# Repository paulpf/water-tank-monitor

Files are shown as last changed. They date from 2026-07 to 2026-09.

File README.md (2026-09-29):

# Water Tank Monitor (D1 Mini / ESP8266)

ESP8266-basierter Wasserstand-Monitor für den Longzhuo TL-136 Flüssigkeitsstand-Messumformer (4-20 mA, 12-32 VDC).
Liest den Tankfüllstand über einen ADS1115 (I2C) aus und veröffentlicht Füllstand, Höhe, Volumen und Diagnosewerte per MQTT
(z. B. für ioBroker). WiFi-Konnektivität und OTA-Updates sind eingebaut.

## Inhaltsverzeichnis
- [Hardware](#hardware)
- [Verdrahtung](#verdrahtung)
- [Funktionsprinzip 4-20 mA](#funktionsprinzip-4-20-ma)
- [Projektstruktur](#projektstruktur)
- [Konfiguration](#konfiguration)
- [Build und Upload](#build-und-upload)
- [MQTT](#mqtt)
- [Serial-Ausgabe](#serial-ausgabe)
- [Fehlersuche](#fehlersuche)
- [OTA-Updates](#ota-updates)
- [Security](#security)
- [Tests und CI](#tests-und-ci)

---

## Hardware

| Bauteil | Beschreibung |
|---|---|
| WeMos D1 Mini | ESP8266-Mikrocontroller, 3,3 V Logik |
| Longzhuo TL-136 | 2-Draht 4-20 mA Füllstandssensor, 12-32 VDC Loop-Speisung |
| Boost-Converter | 5 V USB → 24 V DC für den Sensor-Loop (Trimmer auf 24 V einstellen) |
| 4-20 mA Empfänger | Wandelt Stromsignal in Spannung: I+ / I– Eingang, 0–3,3 V Ausgang |
| ADS1115 | 16-Bit I²C ADC (Adafruit), I²C-Adresse 0x48 (ADDR → GND), GAIN_ONE ±4,096 V |

> **Auflösung:** ADS1115 liefert 0,125 mV/Bit (16-Bit) statt 3,2 mV/Bit des ESP8266-internen ADC — 25× besser.  
> **Kein separates Netzteil nötig:** Der Boost-Converter erzeugt die 24 V Loop-Spannung direkt aus USB 5 V.

---

## Platinenlayout / Verdrahtung

Bestückung und Brücken

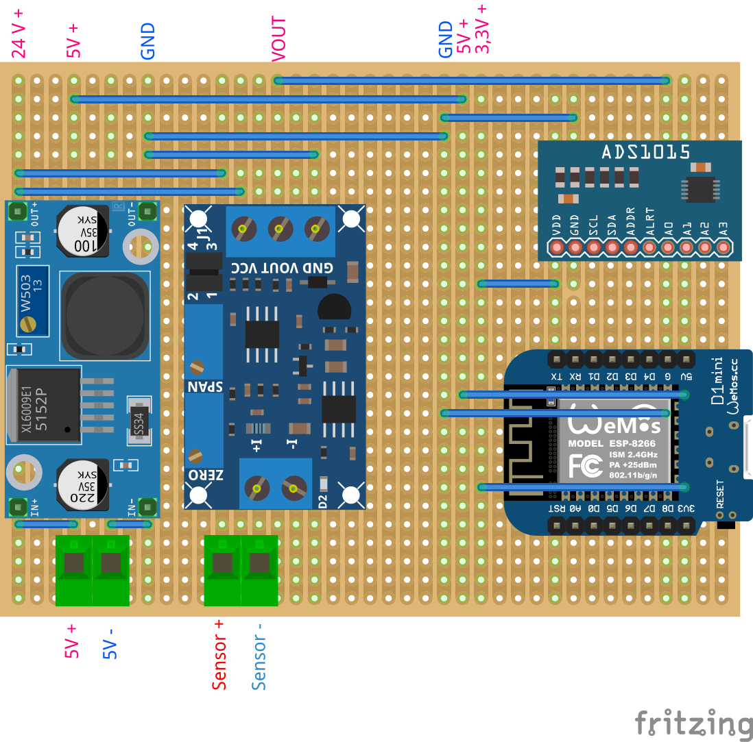
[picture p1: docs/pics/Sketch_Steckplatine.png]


Trennungsstellen der Leiterbahnen (Cut-Lines) auf der Platine

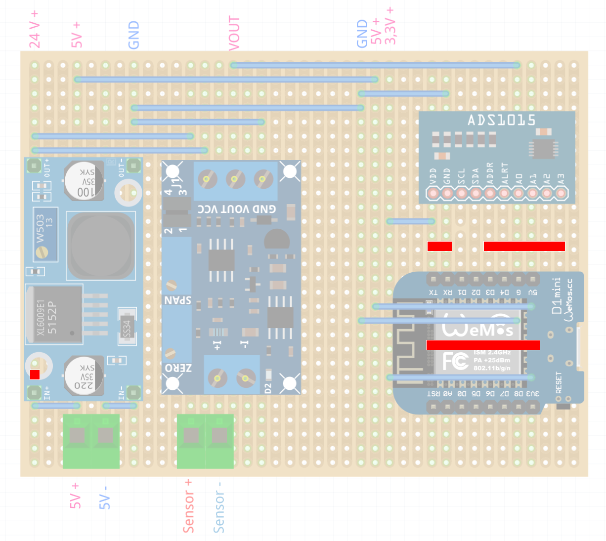
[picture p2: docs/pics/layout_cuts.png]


### Klemmbelegung Schritt für Schritt

| Schritt | Von | Nach | Beschreibung |
|---|---|---|---|
| 1 | D1 Mini **5V-Pin** | Boost-Converter IN+ | 5V vom USB-VBUS (Polyfuse 500 mA, passt) |
| 2 | Boost-Converter OUT+ (24 V) | TL-136 Braun (+) | Loop-Spannung |
| 3 | TL-136 Blau (–) | Empfänger I+ | 4-20 mA Signal |
| 4 | Empfänger I– | GND-Schiene | Loop-Rückleitung |
| 5 | Empfänger Vout | ADS1115 **A0** | Spannungssignal 0–3,3 V |
| 6 | ADS1115 **SCL** | D1 Mini **D1** | I²C Takt |
| 7 | ADS1115 **SDA** | D1 Mini **D2** | I²C Daten |
| 8 | ADS1115 **VDD** | D1 Mini **3V3** | ADS1115 Versorgung |
| 9 | ADS1115 **ADDR** | GND-Schiene | I²C-Adresse 0x48 |
| 10 | D1 Mini **GND** | GND-Schiene | Gemeinsame Masse |
| 11 | USB-Kabel | D1 Mini (Micro-USB) | Einzige externe Stromquelle |

> **GND-Schiene:** Boost-Converter-GND, Empfänger-GND, ADS1115-GND und D1-Mini-GND müssen alle verbunden sein.  
> **Strombudget:** ESP8266 ~170 mA + Boost ~57 mA + Rest ~6 mA = ~230 mA gesamt — USB 2.0 (500 mA) hat ausreichend Reserve.

### Kalibrierung des Signalempfängers

Der 4-20 mA Empfänger hat zwei Trimmer: **ZERO** (Nullpunkt) und **SPAN** (Vollausschlag).
Ziel: 4 mA → 0,00 V, 20 mA → SPAN-Trimmer auf Maximum drehen und gemessenen Wert in `config.h` eintragen (dieser Receiver: **3,153 V**).

#### Schritt 1 – ZERO einstellen (Nullpunkt, leerer Tank)

> **Wichtig:** ZERO kalibriert den **4 mA-Punkt**. Ohne Sensor oder Widerstand-Simulator fließt kein Strom im Loop — der Trimmer lässt sich dann nicht sinnvoll einstellen.

- Multimeter (DC-Spannung) zwischen **VOUT** und **GND** der Receiver-Platine klemmen
- Tank leeren (Sensor angeschlossen) **oder** Widerstand-Simulator für 4 mA an **I+** / **I–** anschließen (s. u.)
- **ZERO-Trimmer** drehen bis Spannung an **VOUT** = **0,00 V**
- Drehrichtung: **Uhrzeigersinn erhöht** die Ausgangsspannung (bei den meisten Modulen) —  
  kurze Probedrehung machen und Multimeter beobachten; bei falschem Effekt Richtung umkehren

#### Schritt 2 – SPAN einstellen (Vollausschlag, voller Tank)

- Tank füllen **oder** 20 mA in **I+** / **I–** einspeisen (Widerstand-Simulator, s. u.)
- **SPAN-Trimmer** drehen bis Spannung an **VOUT** = **3,30 V**
- Drehrichtung: ebenfalls **Uhrzeigersinn erhöht** — kurze Probedrehung zur Verifikation

#### Schritt 3 – Iterieren

ZERO und SPAN beeinflussen sich gegenseitig leicht.  
Schritte 1 und 2 zwei- bis dreimal wiederholen bis beide Punkte stabil sind.

#### Trimmer und Potentiometer prüfen (vor dem Einbau)

Vor der Kalibrierung sicherstellen, dass Trimmer und Poti (für Simulator-Schaltung) intakt sind:

1. **Gesamtwiderstand messen** — Multimeter auf Ω, die beiden äußeren Anschlüsse messen:  
   Soll = Aufdruck (z. B. 5 kΩ, 10 kΩ). Abweichung > 20 % → Bauteil defekt.

2. **Schleifer auf Gleichmäßigkeit prüfen** — Multimeter auf Ω zwischen Schleifer (Mittelanschluss) und einem äußeren Anschluss, Trimmer/Poti langsam von Anschlag zu Anschlag drehen:  
   Wert soll sich **kontinuierlich und gleichmäßig** ändern (0 Ω bis Maximalwert).  
   Sprünge oder tote Bereiche → Bauteil verbraucht oder oxidiert → tauschen.

3. **Auf Unterbrechung testen** — Multimeter auf Durchgang (Piepton-Modus), Schleifer auf Mitte stellen, alle drei Anschlüsse paarweise prüfen: jedes Paar sollte Durchgang haben.

#### 4 mA und 20 mA simulieren ohne Tank

TL-136 abstecken, Widerstand in den Loop schalten:

```
Boost OUT+ (24 V) → [R_sim] → Multimeter (mA) → I+  [Receiver]  I– → GND
```

```
I = U / R    →    R = U / I

4 mA  (ZERO): R = 24 V / 4 mA  = 6000 Ω  → 5,6 kΩ + 390 Ω in Reihe
20 mA (SPAN): R = 24 V / 20 mA = 1200 Ω  → 1 kΩ + 200 Ω in Reihe

Achtung: 560 Ω wären bei 24 V ≈ 42 mA → Receiver-Schaden!
```

Multimeter in Reihe (Strommessung) ist die präziseste Methode — Widerstandstoleranzen ausgleichen durch Iterieren.

#### Hinweis: ZERO-Drift bei 24 V

Bei 24 V Loop-Spannung kann der ZERO-Punkt leicht über 0 V liegen.  
Liegt **VOUT** bei leerem Tank z. B. auf 0,05 V statt 0,00 V,  
den ZERO-Trimmer so weit wie möglich gegen 0 V trimmen — der Rest wird durch die **Software-Kalibrierung** (s. u.) korrigiert.

---

## Funktionsprinzip 4-20 mA

Der TL-136 ist ein **2-Draht Loop-Transmitter**: Er moduliert den Strom im
Loop proportional zum Füllstand. Der **4-20 mA Signalempfänger** wandelt
diesen Strom in eine Spannung um, die der **ADS1115** (Kanal A0, 16 Bit, `GAIN_ONE` = ±4,096 V, 0,125 mV/Bit) misst.

| Loop-Strom | Spannung an ADS1115 A0 (kalibriert, `SENSOR_VREF` = 3,153 V) |
|---|---|
| 4 mA | 0,000 V |
| 8 mA | 0,788 V |
| 12 mA | 1,577 V |
| 16 mA | 2,365 V |
| 20 mA | 3,153 V |

**Umrechnung** (in [src/domain/tankmodel.cpp](src/domain/tankmodel.cpp)):

```
Strom    = (Spannung / SENSOR_VREF) × 16 + 4          [mA]  ← nur für Diagnose und Gültigkeitsprüfung
Höhe     = Kalibriertabelle SENSOR_CAL_TABLE(Spannung) [cm]  ← gesamte Wasserhöhe ab Tankboden
Füllstand = (Höhe − 13 cm) / (210 cm − 13 cm) × 100    [%]   ← 0 % = Sensorposition, 100 % = Ablauf
Volumen  = Zylinder (r = 1 m) bis 198 cm, darüber linear bis 6500 L bei 210 cm   [L]
Überlauf = Volumen − 6500 L, falls positiv                [L]
```

Die Höhe folgt nicht linear aus dem Strom, sondern aus gemessenen Stützpunkten (siehe
[Software-Kalibrierung](#software-kalibrierung-kalibriertabelle)). Oberhalb 210 cm kann der Füllstand über 100 % steigen.

Werte außerhalb 3,8–20,5 mA werden als Sensor-/Verdrahtungsfehler geloggt, per MQTT als `tank/valid = false`
gemeldet und die Messwerte (Füllstand, Höhe, Volumen) dann nicht veröffentlicht.

---

## Projektstruktur

```text
water-tank-monitor/
├── src/
│   ├── app/
│   │   ├── application.cpp / .h    # Hauptschleife: Timer, Publizieren, MQTT-Befehle
│   │   └── main.cpp                # Objekte anlegen, setup()/loop()
│   ├── config/
│   │   ├── config.h                # Konstanten: Topics, Timings, Sensor, Tankgeometrie, Kalibriertabelle
│   │   └── systemconfig.h          # Zur Laufzeit per MQTT änderbare Werte
│   ├── domain/                     # Reine Logik ohne Arduino, nativ getestet
│   │   ├── tankmodel.cpp / .h      # Spannung → Strom, Höhe, Prozent, Volumen, Überlauf
│   │   ├── tanklevel.h             # Wertobjekt eines Messwerts
│   │   ├── mqttcommands.cpp / .h   # Payload-Parser für Intervall und 0/1
│   │   └── intervaltimer.h         # millis()-überlaufsicherer Intervall-Timer
│   └── infrastructure/             # Hardware und Netzwerk
│       ├── levelsensor.cpp / .h    # ADS1115 auslesen
│       ├── wifimanager.cpp / .h    # WLAN verbinden; Reconnect macht das SDK, Fallback nach 5 min
│       ├── mqttmanager.cpp / .h    # MQTT folgt dem WLAN-Zustand, LWT, Re-Subscribe
│       ├── otamanager.cpp / .h     # ArduinoOTA, fail-closed ohne Passwort
│       ├── watchdog.cpp / .h       # Software-Watchdog
│       └── trace.cpp / .h          # Serial-Logging
├── test/native/                    # Unity-Tests für src/domain
├── scripts/
├── platformio.ini
└── README.md
```

Externe Secrets (nicht im Repo):
```text
../_secrets/
├── WifiSecret.h        # WIFI_SSID, WIFI_PWD
├── MqttSecret.h        # MQTT_USER, MQTT_PWD
├── OtaSecret.h         # OTA_PASSWORD
└── last_ota_ip.txt     # zuletzt verwendete OTA-IP (automatisch)
../_config/
└── MqttConfig.h        # MQTT_SERVER_IP, MQTT_SERVER_PORT
```
Anlegen mit `scripts/setup_secrets.ps1` bzw. `scripts/setup_secrets.sh`.

---

## Konfiguration

Alle Konstanten liegen in [src/config/config.h](src/config/config.h).

### Sensor-Parameter

```cpp
constexpr uint8_t  SENSOR_ADS_I2C_ADDR      = 0x48;   // ADDR-Pin → GND
constexpr uint8_t  SENSOR_ADS_CHANNEL       = 0;      // ADS1115 Kanal A0
constexpr float    SENSOR_VREF              = 3.153f; // gemessener Vollausschlag des Empfängers (20 mA) [V]
constexpr uint32_t SENSOR_READ_INTERVAL_MS  = 500;    // Standard-Leseintervall, per MQTT änderbar
constexpr uint32_t MQTT_PUBLISH_INTERVAL_MS = 1000;   // Standard-Sendeintervall, per MQTT änderbar
```

`SENSOR_VREF` wird nur für den Stromwert (`currentMa`) und die Gültigkeitsprüfung (3,8–20,5 mA) verwendet.
Voraussetzung: Der Signalempfänger ist auf **4 mA → 0 V** kalibriert (ZERO/SPAN-Trimmer, s. Abschnitt
[Kalibrierung des Signalempfängers](#kalibrierung-des-signalempfängers)).

### Software-Kalibrierung (Kalibriertabelle)

Die Wasserhöhe wird über die Tabelle `SENSOR_CAL_TABLE` in `config.h` aus der Spannung berechnet: zwischen zwei Punkten
linear interpoliert, unterhalb des ersten Punkts auf die Sensorhöhe begrenzt, oberhalb des letzten mit der Steigung des
letzten Abschnitts extrapoliert. Höhe ist die gesamte Wasserhöhe ab Tankboden (wie mit dem Maßband gemessen).

```cpp
constexpr SensorCalPoint SENSOR_CAL_TABLE[] = {
    { 0.000f,  13.0f },   // Sensorposition
    { 0.2277f, 20.0f },   // gemessen
    { 2.2419f, 210.0f },  // gemessen
    ...
};
```

**Neuen Messpunkt aufnehmen:**

1. Kalibriermodus einschalten: `1` auf `water-tank-monitor/config/calibrationMode/set` (Werte alle 500 ms)
2. Wasserhöhe mit dem Maßband messen
3. Spannung aus `water-tank-monitor/tank/voltageV` ablesen
4. Punkt `{ Spannung, Höhe }` in `SENSOR_CAL_TABLE` einfügen (Spannungen aufsteigend sortiert)
5. `pio test -e native` ausführen (prüft u. a. alle Tabellenpunkte), Firmware bauen und flashen
6. Kalibriermodus ausschalten: `0` auf `.../calibrationMode/set`

### Libraries

Versionen sind in `platformio.ini` exakt festgelegt (Adafruit ADS1X15, Adafruit BusIO, PubSubClient) und werden
automatisch über PlatformIO installiert.

### WiFi Credentials

Datei: `../_secrets/WifiSecret.h`
```cpp
#define WIFI_SSID "DEIN_NETZWERK"
#define WIFI_PWD  "DEIN_PASSWORT"
```

### OTA-Passwort

Datei: `../_secrets/OtaSecret.h`
```cpp
#define OTA_PASSWORD "dein_ota_passwort"
```

OTA ist **fail-closed**: ohne gesetztes Passwort und
`OTA_ALLOW_INSECURE_NO_PASSWORD false` bleibt OTA deaktiviert.

---

## Build und Upload

### USB (erstmaliger Flash)

```powershell
pio run -e d1-mini-usb
pio run -e d1-mini-usb -t upload -t monitor --upload-port COM3
```

### OTA (Folge-Updates)

Interaktives PowerShell-Skript (fragt IP ab, liest OTA-Passwort automatisch):

```powershell
.\scripts\upload_ota.ps1
```

Alternativ (Windows Batch):
```bat
scripts\upload_ota.bat
```

Die zuletzt verwendete IP wird in `../_secrets/last_ota_ip.txt` gespeichert.

---

## MQTT

Alle Topics beginnen mit `water-tank-monitor/`. Werte veröffentlicht das Gerät retained, außer `system/rssi`.

| Topic | Inhalt |
|---|---|
| `tank/levelPercent`, `tank/heightCm`, `tank/volumeLiters`, `tank/volumeOverflowLiters` | Messwerte (nur bei gültigem Sensorwert) |
| `tank/currentMa`, `tank/voltageV`, `tank/valid` | Rohwerte und Gültigkeit (`true`/`false`) |
| `system/health` | JSON mit Sensor-, WLAN-, Heap- und OTA-Status |
| `system/ip`, `system/rssi` | IP-Adresse, WLAN-Signalstärke |
| `system/status` | `online`, bzw. `offline` als Last Will |
| `config/readIntervalMs`, `config/publishIntervalMs`, `config/calibrationMode` | aktuelle Einstellungen |

Befehle (auf das jeweilige Topic schreiben):

| Topic | Gültige Werte |
|---|---|
| `config/readIntervalMs/set`, `config/publishIntervalMs/set` | nur Ziffern, ohne führende Null, ab 500 (ms); sehr große Werte (bis 4294967295) setzen Lesen bzw. Senden praktisch aus |
| `config/calibrationMode/set` | `1` (Lesen und Senden alle 500 ms) oder `0` |
| `command/reset` | `1` startet das Gerät neu, alles andere wird ignoriert |

Ungültige Werte werden ignoriert und im Serial-Log als Warnung gemeldet. Frühere Firmware-Versionen haben z. B. `12abc`
als 12 ms übernommen, Werte unter 500 ms akzeptiert und den Rohtext ins State-Topic zurückgeschrieben.

---

## Serial-Ausgabe

Baud: **115200**

```
[INFO] Application setup started
[INFO] ADS1115 ready
[INFO] MqttManager setup complete
[INFO] Application setup complete
[INFO] WiFi connected, IP: 192.168.178.42
[INFO] Setting up OTA...
[INFO] OTA initialized successfully
[INFO] MQTT connecting...
[INFO] MQTT connected
[INFO] MQTT connected - publishing initial values
[INFO] Tank: 47.3% | 106.1 cm | 3333 L | 11.57 mA
[WARNING] Sensor out of range: 0.00 mA - check wiring    ← Kabel offen oder Kurzschluss
```

---

## Fehlersuche

### Messpunkte & Sollwerte

Alle Spannungen gegen GND-Schiene. Multimeter DC-Volt, Loop-Strom in Reihe.

| Messpunkt | Instrument | Sollwert |
| --- | --- | --- |
| Boost OUT+ | Multimeter | **24 V ±0,5 V** |
| Loop-Strom (in Reihe) | Multimeter mA | **4–20 mA** |
| Receiver **VOUT** | Multimeter | **0,00–3,30 V** (proportional zum Füllstand) |
| ADS1115 A0 | Multimeter | identisch mit Receiver **VOUT** |
| ADS1115 VDD | Multimeter | **3,30 V ±0,1 V** |
| ADS1115 ADDR | Multimeter | **0 V** (→ I²C-Adresse 0x48) |
| I²C SCL (D1 Mini D1) | Oszi | **100 kHz** Takt, aktiv beim Lesen |
| I²C SDA (D1 Mini D2) | Oszi | Datenpulse synchron mit SCL |
| Boost OUT+ Ripple | Oszi AC-Kopplung | **< 200 mV pp** |

---

### Fehlerbild: `[WARNING] Sensor out of range: … mA - check wiring`

Tritt auf wenn `currentMa < 3,8` oder `currentMa > 20,5`. Schritt für Schritt eingrenzen:

```
1. Boost-Converter prüfen
   → Multimeter an OUT+ vs GND
   → < 20 V?  → Trimmer nachstellen oder Boost defekt
   → 0 V?     → D1 Mini 5V-Pin prüfen (USB-Verbindung, Polyfuse)

2. Loop-Strom prüfen
   → Multimeter (mA) in Serie: TL-136(–) Blau → Receiver I+
   → 0 mA?    → Offener Kreis: Kabel gebrochen oder TL-136 defekt
   → > 21 mA? → TL-136 übersteuert oder Kurzschluss im Loop
   → 4–20 mA? → Loop OK → weiter mit Schritt 3

3. Receiver-Ausgang prüfen
   → Multimeter (DC-V) an VOUT vs GND der Receiver-Platine
   → 4 mA im Loop → VOUT sollte ~0,0 V sein
   → 20 mA im Loop → VOUT sollte ~3,3 V sein
   → Abweichung → ZERO/SPAN-Trimmer nachjustieren (siehe Kalibrierung)

4. ADS1115-Versorgung prüfen
   → VDD = 3,3 V?
   → ADDR = 0 V? (I²C-Adresse 0x48)
   → GND mit D1 Mini GND verbunden?

5. I²C-Bus prüfen
   → Oszi an SCL (D1) und SDA (D2), Trigger: fallende Flanke SCL
   → Kein Signal → Kabel unterbrochen oder ADS1115 defekt
   → Signal vorhanden → I²C läuft, Firmware-Problem unwahrscheinlich
```

---

### Fehlerbild: Wert springt oder ist verrauscht

**Boost-Ripple (Oszi, AC-Kopplung, 50 mV/div, 20 µs/div):**

- Ripple > 500 mV pp → 100 µF / 25 V Elko direkt an Boost OUT+/GND nachrüsten
- Spitzen synchron mit WiFi-Bursts (alle ~100 ms) → zusätzlich 100 µF an D1 Mini 5V/GND

**I²C-Signalqualität (Oszi, 2 V/div, 5 µs/div):**

- Flanken stark abgerundet → Pull-up-Widerstand fehlt oder zu groß → 4,7 kΩ von SCL/SDA nach 3,3 V
- Idealbild: steile Rechteckflanken, 100 kHz, High-Pegel ~3,3 V

---

### Fehlerbild: Angezeigter %-Wert weicht vom tatsächlichen Füllstand ab

Kalibrierungstabelle in `src/config/config.h` ergänzen:

1. Loop-Strom mit Multimeter auf einen bekannten Wert einstellen (z. B. 12 mA = 50 %)
2. Receiver **VOUT** messen → dieser Spannungswert ist der neue Tabellenpunkt
3. Tatsächliche Gesamthöhe ab Tankboden (Maßband) notieren
4. Eintrag in `SENSOR_CAL_TABLE` hinzufügen: `{ gemessene_V, tatsächliche_Höhe_cm }`
5. Firmware neu bauen und flashen

Mehr Stützpunkte = genauere Kurve. Punkte müssen aufsteigend nach Spannung sortiert sein.

---

### TL-136 ohne Wasser simulieren (Widerstands-Methode)

TL-136 abstecken, Widerstand + Multimeter (mA) in Reihe in den Loop einsetzen:

```
Boost OUT+ (24 V) → [R_sim] → Multimeter (mA) → Receiver I+ → Receiver I– → GND
```

| Simulation | Strom | R_gesamt | Praktischer Wert |
| --- | --- | --- | --- |
| Leerer Tank (ZERO) | 4 mA | 6000 Ω | 5,6 kΩ + 390 Ω |
| Halbvoll | 12 mA | 2000 Ω | 1,8 kΩ + 180 Ω |
| Voller Tank (SPAN) | 20 mA | 1200 Ω | 1 kΩ + 180 Ω |

> Widerstandswert immer mit Multimeter (mA in Reihe) verifizieren — Receiver-Innenwidertand (~150–250 Ω) ist bereits eingerechnet.  
> **Achtung:** 560 Ω wären bei 24 V ≈ 42 mA → Receiver-Schaden.

---

### Schnell-Checkliste

```
□ Boost OUT+ = 24 V DC
□ Loop-Strom mit angeschlossenem Sensor: 4–20 mA
□ Receiver VOUT bei 4 mA  → 0,00 V (ZERO-Trimmer)
□ Receiver VOUT bei 20 mA → 3,153 V (SPAN-Trimmer Maximum, gemessen)
□ ADS1115 VDD = 3,30 V
□ ADS1115 ADDR = 0 V (Adresse 0x48)
□ I²C SCL aktiv beim Lesen (Oszi)
□ Boost-Ripple < 200 mV pp (Oszi, AC-Kopplung)
□ Serial: kein [WARNING] bei korrektem Loop-Strom
```

---

## OTA-Updates

Skript `scripts/upload_ota.ps1`:
- Liest `OTA_PASSWORD` direkt aus `../_secrets/OtaSecret.h`
- Fragt die Geräte-IP ab (letzter Wert als Vorschlag)
- Startet `pio run -e d1-mini-ota -t upload --upload-port <IP>`

---

## Security

- OTA nur in vertrauenswürdigen Netzen aktivieren
- Keine Secrets ins Repository committen
- `OTA_PASSWORD` immer setzen (`OTA_ALLOW_INSECURE_NO_PASSWORD false`)
- Bei WLAN-Ausfall: automatischer Reconnect durch das ESP8266-SDK; nach 5 min ohne Verbindung startet die Firmware den Verbindungsaufbau neu

---

## Tests und CI

```powershell
pio run -e d1-mini-usb          # Firmware-Build
pio test -e native              # Unit-Tests (benötigt gcc/g++ lokal)
```

Die Unit-Tests kompilieren den echten Code aus `src/domain/` für den PC (`test_build_src = yes`):
Kalibrierung und Tankgeometrie, MQTT-Payload-Parser und Intervall-Timer.
Unter Windows liefert z. B. `winget install BrechtSanders.WinLibs.POSIX.UCRT` den nötigen gcc/g++.

CI-Workflow: `.github/workflows/ci.yml` (Firmware-Build und Unit-Tests bei Push auf `main` und bei Pull Requests auf `main`)

### Build-Cache leeren

```powershell
Remove-Item -Recurse -Force .pio\build
```

---

## Referenzen

- [Arduino Core für ESP8266](https://github.com/esp8266/Arduino)
- [ArduinoOTA (ESP8266)](https://arduino-esp8266.readthedocs.io/en/latest/ota_updates/readme.html)
- [PlatformIO](https://platformio.org)
- [WeMos D1 Mini Pinout](https://www.wemos.cc/en/latest/d1/d1_mini.html)

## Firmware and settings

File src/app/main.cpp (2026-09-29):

#include "application.h"
#include "config.h"

WifiManager wifiManager;
OtaManager otaManager;
SystemConfig systemConfig;
LevelSensor levelSensor;
MqttManager mqttManager;
Watchdog watchdog;
Application app(wifiManager, otaManager, systemConfig, levelSensor, mqttManager, watchdog);

void setup()
{
  Serial.begin(SERIAL_BAUD_RATE);
  delay(SERIAL_STARTUP_DELAY_MS);

  app.setup();
}

void loop()
{
  app.loop();
}

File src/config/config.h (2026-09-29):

#ifndef CONFIG_H
#define CONFIG_H

#include <stdint.h>

// Compile-time configuration: device identity, timings, MQTT topics,
// sensor hardware and tank geometry. Secrets live outside the repository
// (../_secrets, ../_config), see scripts/setup_secrets.*.

// Serial configuration
#define SERIAL_BAUD_RATE 115200
constexpr uint32_t SERIAL_STARTUP_DELAY_MS = 500;

// System timings (in milliseconds)
#define WATCHDOG_TIMEOUT 30000

// Trace level for logging
#define TRACE_LEVEL TraceLevel::INFO

// OTA configuration
#define ENABLE_OTA true
#if defined(ARDUINO_ARCH_ESP8266)
constexpr uint16_t OTA_PORT = 8266;
#else
constexpr uint16_t OTA_PORT = 3232;
#endif
// Security default: fail closed if no OTA password is configured
#define OTA_ALLOW_INSECURE_NO_PASSWORD false

// Device identity
#define DEVICE_NAME "water-tank-monitor"

// WiFi configuration
// The SDK auto-reconnects; after this long without WiFi the firmware calls
// WiFi.begin() again as a fallback (and repeats at this interval).
constexpr uint32_t WIFI_FALLBACK_BEGIN_MS = 5UL * 60UL * 1000UL;

// Application loop behavior
constexpr uint32_t STATUS_PRINT_INTERVAL_MS = 30000;

// MQTT configuration
constexpr uint32_t MQTT_RETRY_INTERVAL_MS  = 5000;
#define MQTT_TOPIC_LEVEL_PERCENT       DEVICE_NAME "/tank/levelPercent"
#define MQTT_TOPIC_HEIGHT_CM           DEVICE_NAME "/tank/heightCm"
#define MQTT_TOPIC_VOLUME_LITERS       DEVICE_NAME "/tank/volumeLiters"
#define MQTT_TOPIC_VOLUME_OVERFLOW_L   DEVICE_NAME "/tank/volumeOverflowLiters"
#define MQTT_TOPIC_CURRENT_MA          DEVICE_NAME "/tank/currentMa"
#define MQTT_TOPIC_VOLTAGE_V           DEVICE_NAME "/tank/voltageV"
#define MQTT_TOPIC_VALID               DEVICE_NAME "/tank/valid"
#define MQTT_TOPIC_READ_INTERVAL_MS    DEVICE_NAME "/config/readIntervalMs"        // state (retained, device publishes)
#define MQTT_TOPIC_READ_INTERVAL_SET   DEVICE_NAME "/config/readIntervalMs/set"    // command (write here to change it)
#define MQTT_TOPIC_PUBLISH_INTERVAL_MS  DEVICE_NAME "/config/publishIntervalMs"     // state (retained, device publishes)
#define MQTT_TOPIC_PUBLISH_INTERVAL_SET DEVICE_NAME "/config/publishIntervalMs/set" // command (write here to change it)
#define MQTT_TOPIC_CALIBRATION_MODE     DEVICE_NAME "/config/calibrationMode"       // state (retained, "1"/"0")
#define MQTT_TOPIC_CALIBRATION_MODE_SET DEVICE_NAME "/config/calibrationMode/set"   // command ("1"=on, "0"=off)
constexpr uint32_t CALIBRATION_INTERVAL_MS = 500; // read+publish cadence while calibrationMode is on
#define MQTT_TOPIC_RSSI                DEVICE_NAME "/system/rssi"
#define MQTT_TOPIC_IP                  DEVICE_NAME "/system/ip"
#define MQTT_TOPIC_HEALTH              DEVICE_NAME "/system/health"  // JSON: sensor + system diagnostics
#define MQTT_TOPIC_COMMAND_RESET       DEVICE_NAME "/command/reset"  // payload "1" triggers ESP.restart(), anything else is ignored
constexpr uint32_t MQTT_RSSI_INTERVAL_MS = 5000;

// TL-136 4-20mA level sensor via signal conditioner + ADS1115 (I2C, 16-bit ADC)
// Hardware: USB 5V → Boost converter → 24V loop → TL-136 → 4-20mA receiver
//           → ADS1115 A0 (I2C) → D1 Mini D1/SCL + D2/SDA
// Signal conditioner (SPAN/ZERO trimmer): 4 mA → 0 V, 20 mA → SENSOR_VREF (3.153 V measured)
// ADS1115: ADDR pin to GND → I2C address 0x48
//          GAIN_ONE = ±4.096V range → covers 0–3.3V with 0.125 mV resolution
constexpr uint8_t  SENSOR_ADS_I2C_ADDR      = 0x48;
constexpr uint8_t  SENSOR_ADS_CHANNEL       = 0;      // ADS1115 A0
constexpr float    SENSOR_VREF              = 3.153f; // signal conditioner measured max output [V]
constexpr uint32_t SENSOR_READ_INTERVAL_MS  = 500;     // Default read cadence (calibration); runtime value lives in SystemConfig.sensorReadIntervalMs
constexpr uint32_t MQTT_PUBLISH_INTERVAL_MS = 1000;    // Default publish cadence; runtime value lives in SystemConfig.publishIntervalMs

// Tank geometry (Zisterne Family F 6500)
// Cylinder: 0–198 cm, r=1.0m
// Cone: 198–210 cm (12 cm height)
// Empty (0%): 13 cm height = 408 Liters (sensor position, prevents clogging)
// Full (100%): 210 cm height = 6500 Liters (drain outlet level)
// Critical: 250 cm height (electrical socket danger point; older notes said
//           266 cm - verify on site)
constexpr float TANK_CYLINDER_HEIGHT_CM = 198.0f;
constexpr float TANK_RADIUS_M           = 1.0f;
constexpr float TANK_MIN_HEIGHT_CM      = 13.0f;    // Sensor position (0%)
constexpr float TANK_DRAIN_HEIGHT_CM    = 210.0f;   // Drain outlet (100% normal operation)
constexpr float TANK_MIN_VOLUME_L       = 408.0f;   // Reported volume at/below sensor height
constexpr float TANK_NOMINAL_VOLUME_L   = 6500.0f;  // Volume at drain outlet; above that is overflow
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

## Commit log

2026-05-20 Add TL-136 4-20mA level monitoring via ADS1115 I2C ADC
    - ADS1115 (16-bit, I2C) replaces ESP8266 internal 10-bit ADC (25x better resolution)
    - Signal chain: USB 5V -> Boost converter (12V) -> TL-136 -> 4-20mA receiver -> ADS1115 A0 -> D1 Mini D1/D2 (I2C)
    - LevelSensor reads ADS1115 via Adafruit ADS1X15 library (GAIN_ONE, channel A0)
    - ILevelSensor interface extended with setup() for I2C init with error reporting
    - Signal conditioner calibrated 4mA->0V / 20mA->3.3V via ZERO/SPAN trimmer
    - Wiring diagram (docs/wiring.drawio) updated with all modules including ADS1115
    - README updated with full pin table, calibration steps and library reference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
    [config.h]
2026-05-20 Simplify power wiring: D1 Mini 5V pin feeds boost converter
    Remove separate USB power block from diagram. D1 Mini 5V pin
    (USB VBUS via polyfuse) is the single 5V source for the boost
    converter. Micro-USB on D1 Mini is the only external connection.
    Update ASCII schematic and wiring table in README accordingly.
2026-05-21 Add stripboard layout docs and hardware reference photos
    75x100mm perfboard plan: component positions, power rails, strip cuts,
    jumper wire list with colors/lengths, soldering sequence, and BOM.
    SVG visual layout with color-coded strips, cuts, and jumper wires.
2026-05-21 Fix module pin positions: boost converter and 4-20mA receiver layout
    - Boost converter (XL6009): corrected to cols 22-29, rows 22-38
    (40mm IN↔OUT = 16 rows, 17mm pin spacing ≈ 7 grid units with note to
    bend pins slightly); added strip cuts at col23 R22 and col23 R38;
    GND routed via single vertical wire in col29 (R1→R22→R38)
    - 4-20mA receiver: corrected from 1×5 to 1×3 header (VCC/VOUT/GND)
    at col19 R17-19; I+/I− are module screw terminals, not header pins
    - SVG: rewrote with consistent coordinate formula x=52+(C-1)*25
    - Spec: updated pin tables, strip cuts, jumper list, and BOM
2026-05-22 Add hardware docs, KiCad project, and stripboard layout plans
    Includes datasheets (D1 Mini, AZ070 sensor, CH340 driver), KiCad schematic
    and PCB files, and veroboard layout plans generated with GitHub Copilot and Codex.
    [projekt.kicad_pcb, projekt.kicad_sch, veroboard_75x100_fullpin_nets.csv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]
2026-05-22 Add MQTT support with sensor publishing, RSSI, calibration table
    - MqttManager with PubSubClient, LWT, session state machine
    - ConnectivityCoordinator bridges WiFi events to MQTT connect/disconnect
    - Publishes tank level and current every 60s, WiFi RSSI every 5s
    - Piecewise linear calibration table (voltage -> actual %) in config.h
    - Kalibrierdoku in README erweitert (ZERO/SPAN-Trimmer + Software-Kalibrierung)
    - platformio.ini refactored: [common] section, both envs als default
2026-06-05 Remove obsolete project files and add new pinout diagram
    - Deleted KiCad project files: projekt.kicad_pcb, projekt.kicad_prl, projekt.kicad_pro, projekt.kicad_sch
    - Removed wiring diagram in Draw.io format
    - Added new pinout diagram for D1 Mini in PDF format
    [projekt.kicad_pcb, projekt.kicad_sch, veroboard_75x100_fullpin_nets.csv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]
2026-06-05 Add IP publishing to MQTT and update documentation for 24V loop configuration
2026-06-05 Initialize sensor readiness in setup and handle uninitialized state in read method
2026-06-07 Add initial PCB design file for water tank monitor project
    [Untitled Sketch.fzz]
2026-06-25 Update PCB design file for water tank monitor project
    [Untitled Sketch.fzz]
2026-07-12 Implement watchdog functionality and enhance MQTT management
    - Added Watchdog class to monitor and reset the device if not fed within a timeout.
    - Updated MqttManager to support dynamic topic subscriptions and callbacks.
    - Refactored Application class to integrate watchdog and improve sensor reading and publishing logic.
    - Enhanced sensor data structure to include voltage, height, and volume metrics.
    - Configurable sensor read and publish intervals via MQTT.
    [config.h]
2026-07-14 Refactor sensor calibration and interpolation methods for height measurement
2026-07-15 Update sensor calibration table for improved height measurement accuracy
2026-07-17 Enhance tank level monitoring by adding overflow measurement and updating calibration references
2026-07-17 Add extrapolated sensor calibration point for height measurement
2026-09-29 Pin platform and library versions
    Exact versions keep builds and firmware size comparisons reproducible
    across the upcoming refactoring. Adafruit BusIO is a transitive
    dependency of ADS1X15 and is pinned explicitly.
2026-09-29 Fix WiFi reconnect stall after millis() wrap-around
    The reconnect deadline was stored as an absolute time and compared with
    millis() >= deadline. If the deadline was computed shortly before the
    32-bit millis() counter wrapped (every ~49.7 days), the comparison stayed
    false for another ~49.7 days and WiFi was never reconnected.
    Store the attempt start time and delay instead and compare the elapsed
    time, which is wrap-safe with unsigned arithmetic.
2026-09-29 Feed software watchdog during OTA transfer
    ArduinoOTA.handle() blocks for the whole firmware transfer while still
    yielding, so the Ticker-based watchdog kept running but loop() could not
    feed it. Uploads taking longer than the 30 s timeout would be aborted by
    a restart. Feed the watchdog on every progress chunk; a stalled transfer
    stops calling onProgress and is still caught.
    Also correct the watchdog comment: on ESP8266 Ticker is an SDK software
    timer that only fires while the code yields, not a hardware interrupt.
2026-09-29 Remove dead code, untangle includes, fix misleading comments
    No behavior change.
    - Delete global_defines.h; each file includes what it uses. This also
    removes the include cycle between trace.h and global_defines.h.
    - Remove unused code: SystemConfig long/middle/short intervals and their
    defines, unused tank geometry constants, Trace level helpers and plot
    functions, OtaManager::setEnabled(), LevelSensor native stubs (never
    built), WifiManager empty ctor/dtor and its unreachable fast-path branch.
    - Trace: one prefix mapping; log() delegates to logf().
    - Include secrets by name via -I ../_config instead of relative paths.
    - Fix comments: reset topic only reacts to 1; calibration table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
    [config.h]
2026-09-29 Extract tank math into a testable TankModel
    Move the voltage -> height -> percent/volume/overflow conversion from
    levelsensor.cpp into src/domain/tankmodel.* without any Arduino
    dependency. LevelSensor now only reads the ADS1115 and calls
    TankModel::fromVoltage().
    - Interpolation and extrapolation share one code path (pick segment,
    then interpolate); arithmetic is unchanged.
    - Magic numbers become TANK_MIN_VOLUME_L / TANK_NOMINAL_VOLUME_L.
    - TankLevel::notReady() replaces the duplicated placeholder literal.
    - Native env now builds src/domain/*.cpp so tests exercise real code.
    Before this commit, a temporary test compared TankModel against a
    verbatim copy of the old functions for 4201 vol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
    [config.h]
2026-09-29 Simplify connectivity: MqttManager and OtaManager follow WiFi state
    Replace the WiFi event flags, ConnectivityCoordinator, the startup state
    machine in Application and MqttSessionManager with one rule: while WiFi
    is up, MQTT connects (retry every MQTT_RETRY_INTERVAL_MS) and OTA is set
    up once; while WiFi is down, MQTT disconnects.
    - MqttManager::loop(bool wifiConnected) returns true only in the call
    that established a new connection; Application publishes the initial
    values from onMqttConnected(now). A lost connection is reported in one
    call and reconnected in the next, as before, so every reconnect still
    republishes IP, intervals, calibrationMode and the reset seed.
    - OtaManager::c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
    [config.h]
2026-09-29 Slim down Application, add tested command parser and interval timer
    - src/domain/mqttcommands.*: pure parsers for interval and 0/1 payloads,
    used by Application::applyInterval() (one handler for both interval
    topics) and the calibration mode command.
    - src/domain/intervaltimer.h: wrap-safe uint32_t timer replacing the
    four timestamp members. Connection checks still come first, so the
    publish/RSSI timers are not consumed while MQTT is offline.
    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
2026-09-29 README: describe the actual measurement chain
    The "Funktionsprinzip" section still described the ESP8266's internal
    10-bit ADC and a linear level with 3.3 V full scale. Describe the
    ADS1115, SENSOR_VREF = 3.153 V, and the conversion in TankModel:
    calibration table -> height -> percent, volume and overflow.
    Also align the troubleshooting heading with the actual log message.
2026-09-29 Leave WiFi reconnects to the SDK
    The ESP8266 SDK reconnects on its own after a connection loss. The
    manual reconnect (WiFi.disconnect() + begin() after 2 s, 4 s, ... with
    up to 10 attempts) could abort an association that was still in
    progress.
    WifiManager now enables auto-reconnect, only tracks connection changes
    for logging and, as a fallback, calls WiFi.begin() again after
    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
